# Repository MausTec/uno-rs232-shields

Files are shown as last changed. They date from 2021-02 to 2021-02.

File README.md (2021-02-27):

# Arduino RS232 Shields

This repository contains DTE and DCE shields for the Arduino Uno and compatible devices. These shields use the hardware
serial ports and provide a 9 pin serial connector for interfacing with older electronics. Each shield has a few
variants:

- Standard Variant: RS232 exits the back (notch side) of the Arduino
- Reverse Variant: RS232 exits the front (USB side) of the Arduino

## Are these for sale?

Oh you betcha! DIY Kits and assembled shields will be available on [maustec.io](https://maustec.io).

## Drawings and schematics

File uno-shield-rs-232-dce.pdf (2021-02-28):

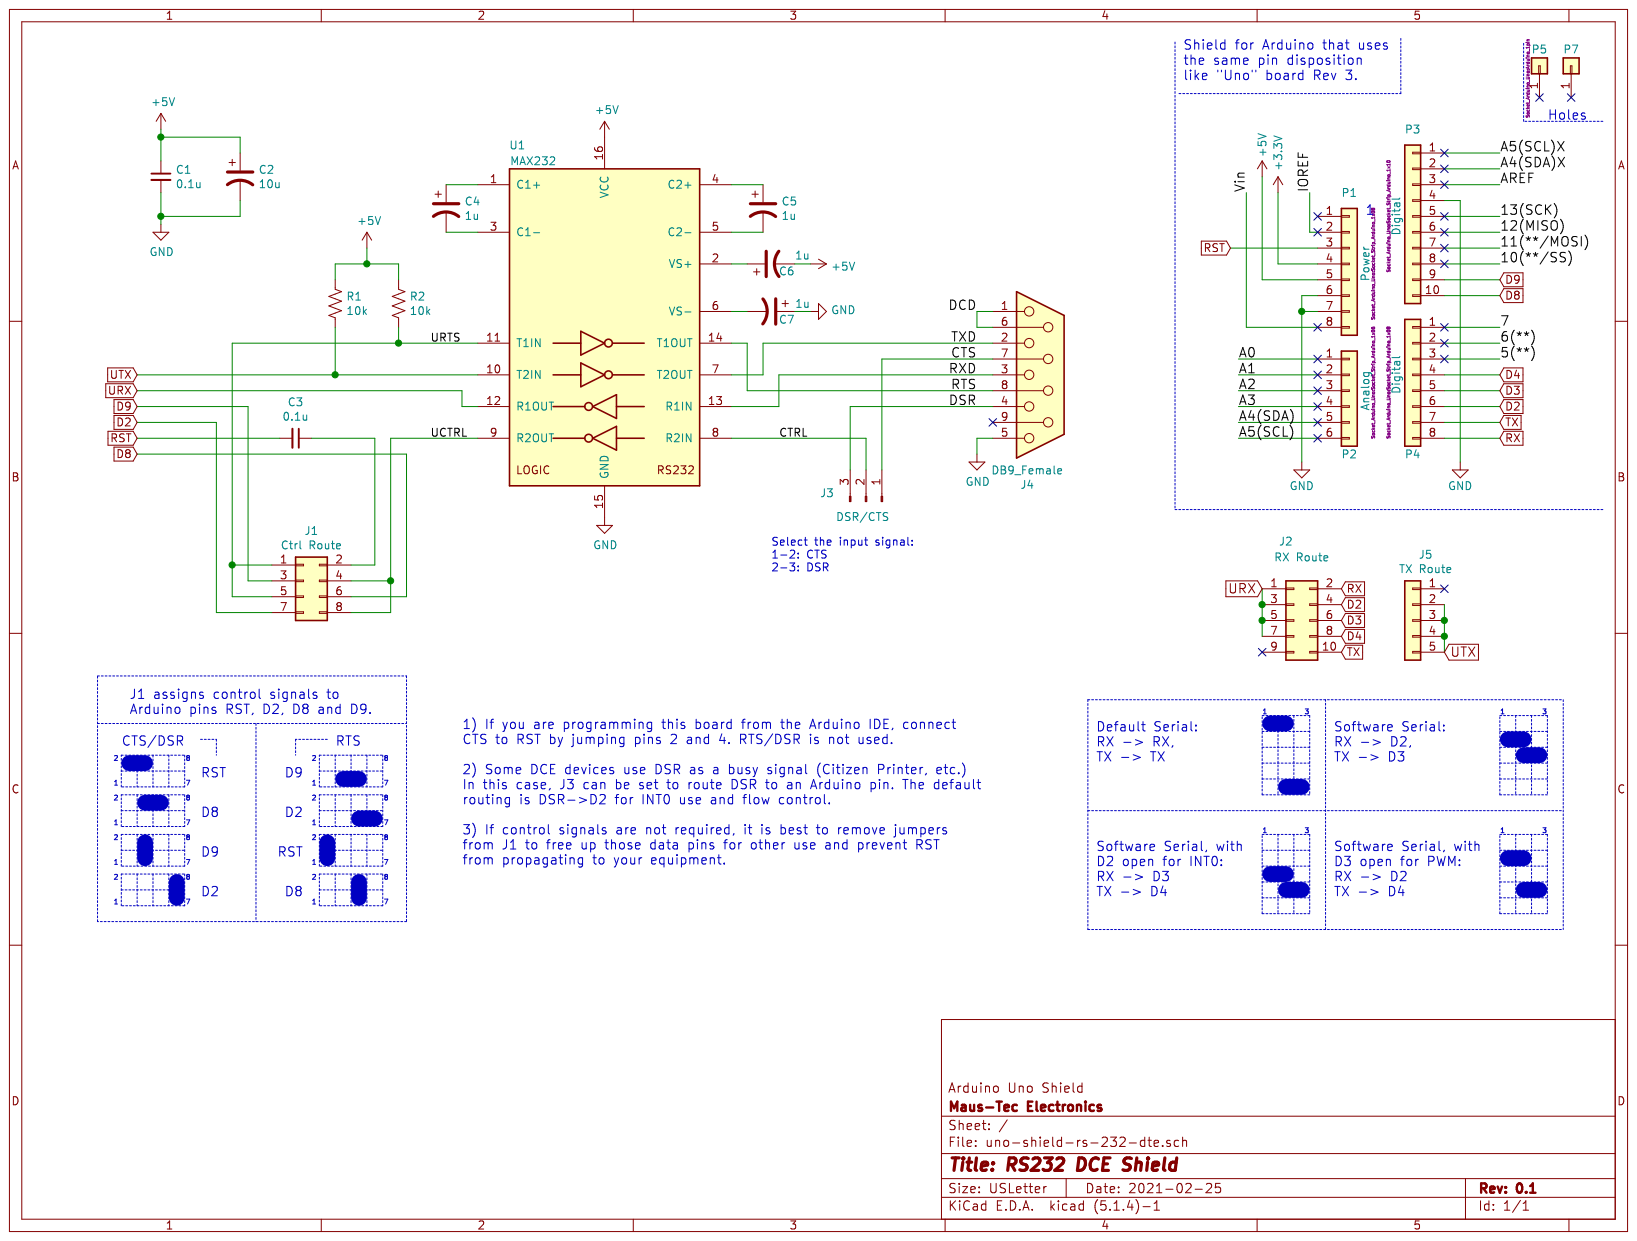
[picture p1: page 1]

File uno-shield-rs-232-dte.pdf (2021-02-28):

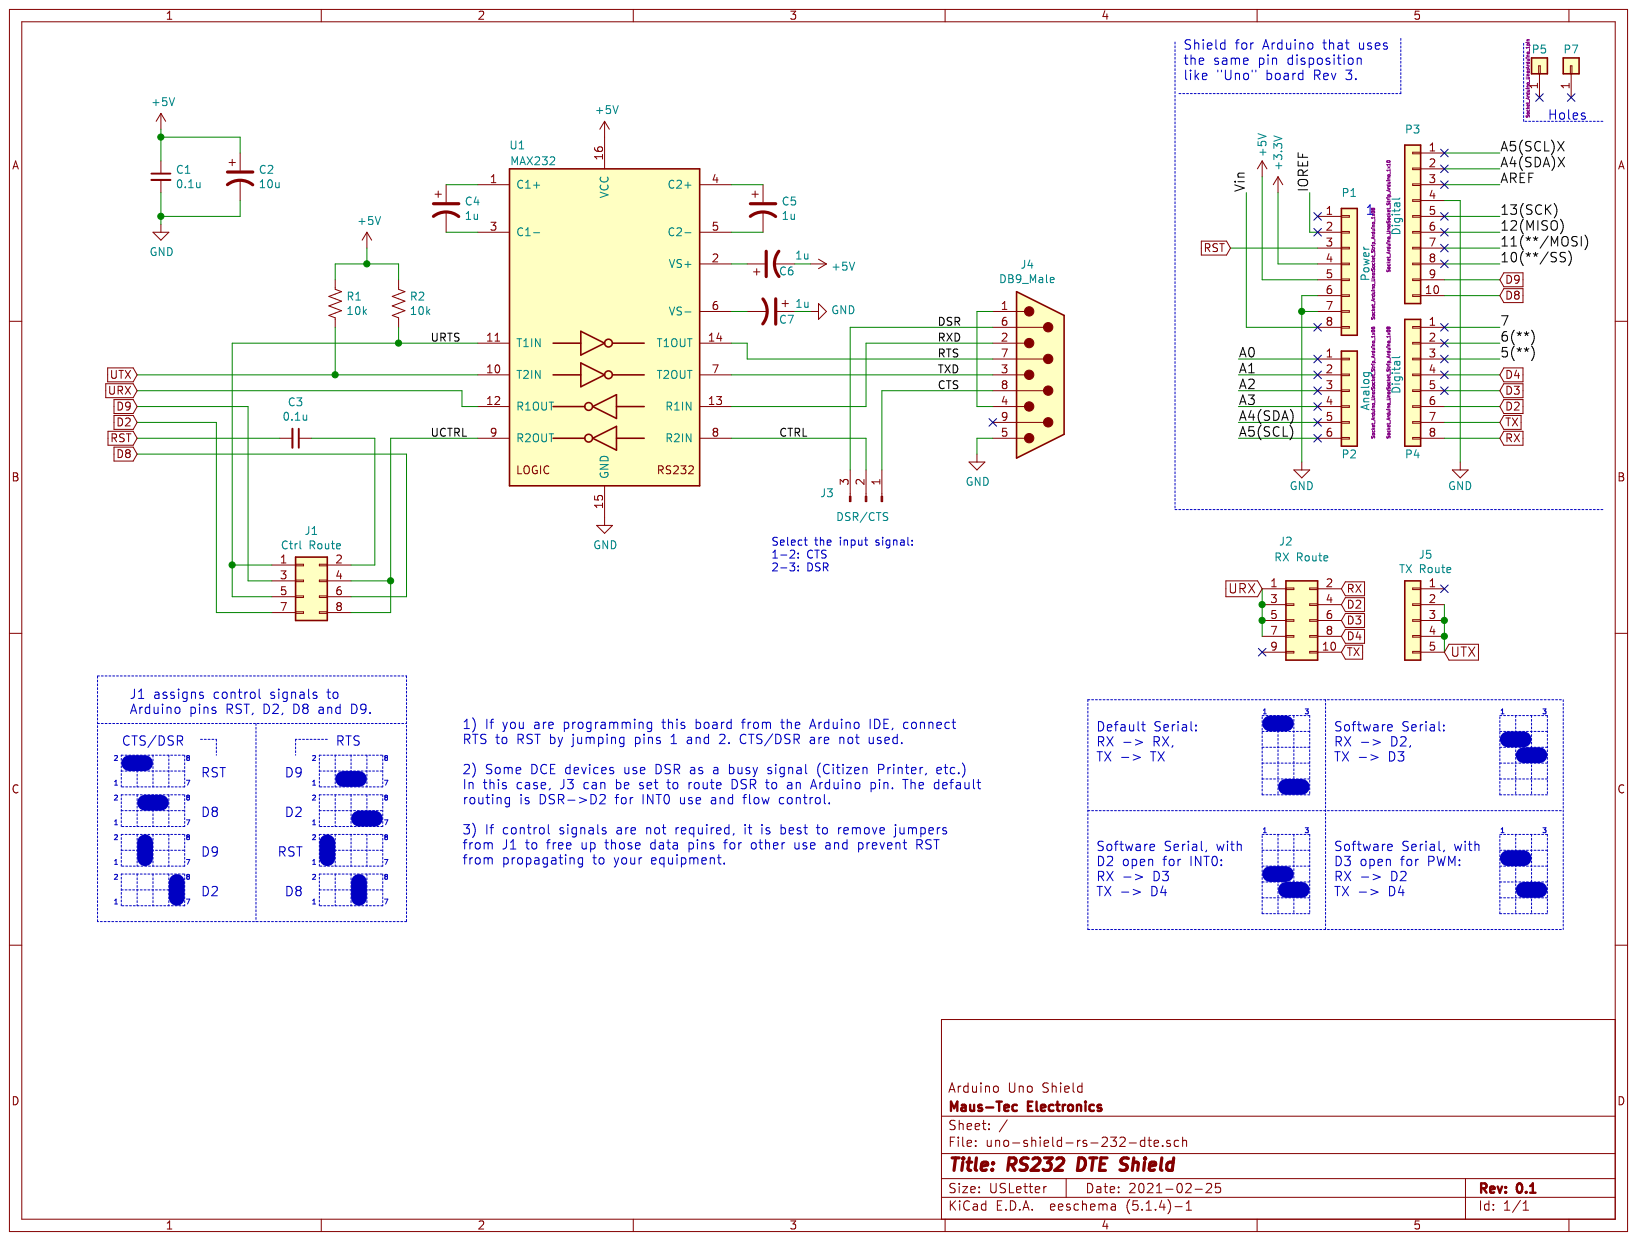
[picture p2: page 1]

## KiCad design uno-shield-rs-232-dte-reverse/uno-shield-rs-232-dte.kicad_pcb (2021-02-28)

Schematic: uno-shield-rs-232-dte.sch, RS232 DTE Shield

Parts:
C1, C3: 0.1u; C_Disc_D5.0mm_W2.5mm_P2.50mm
C2: 10u; CP_Radial_D6.3mm_P2.50mm
C4, C5, C6, C7: 1u; CP_Radial_D4.0mm_P2.00mm
J1: Ctrl Route; PinHeader_2x04_P2.54mm_Vertical
J2: RX Route; PinHeader_2x05_P2.54mm_Vertical
J3: DSR/CTS; PinHeader_1x03_P2.54mm_Vertical
J4: DB9_Male; DSUB-9_Male_Horizontal_P2.77x2.84mm_EdgePinOffset4.94mm_Hou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
J5: TX Route; PinHeader_1x05_P2.54mm_Vertical
P1: Power; Socket_Strip_Arduino_1x08
P2: Analog; Socket_Strip_Arduino_1x06
P3: Digital; Socket_Strip_Arduino_1x10
P4: Digital; Socket_Strip_Arduino_1x08
P5, P7: CONN_01X01; Arduino_1pin
R1, R2: 10k; R_Axial_DIN0207_L6.3mm_D2.5mm_P10.16mm_Horizontal
U1: MAX232; DIP-16_W7.62mm_LongPads

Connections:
+3V3: P1.4
+5V: C1.1, C2.1, C6.2, P1.5, R1.1, R2.1, U1.16 (VCC)
/5(**): P4.3
/6(**): P4.2
/7: P4.1
/10(**/SS): P3.8
/11(**/MOSI): P3.7
/12(MISO): P3.6
/13(SCK): P3.5
/A0: P2.1
/A1: P2.2
/A2: P2.3
/A3: P2.4
/A4(SDA): P2.5
/A4(SDA)X: P3.2
/A5(SCL): P2.6
/A5(SCL)X: P3.1
/AREF: P3.3
/CTRL: J3.2, U1.8 (R2IN)
/CTS: J3.1, J4.8
/DSR: J3.3, J4.6
/IOREF: P1.2
/RTS: J4.7, U1.14 (T1OUT)
/RXD: J4.2, U1.13 (R1IN)
/TXD: J4.3, U1.7 (T2OUT)
/UCTRL: J1.4, J1.8, U1.9 (R2OUT)
/URTS: J1.1, J1.5, R2.2, U1.11 (T1IN)
/Vin: P1.8
D2: J1.7, J2.4, P4.6
D3: J2.6, P4.5
D4: J2.8, P4.4
D8: J1.6, P3.10
D9: J1.3, P3.9
GND: C1.2, C2.2, C7.1, J4.5, P1.6, P1.7, P3.4, U1.15 (GND)
unnamed: C3.1, J1.2
unnamed: C4.1, U1.1 (C1+)
unnamed: C4.2, U1.3 (C1-)
unnamed: C5.1, U1.4 (C2+)
unnamed: C5.2, U1.5 (C2-)
unnamed: C6.1, U1.2 (VS+)
unnamed: C7.2, U1.6 (VS-)
unnamed: J4.1, J4.4
RST: C3.2, P1.3
RX: J2.2, P4.8
TX: J2.10, P4.7
URX: J2.1, J2.3, J2.5, J2.7, U1.12 (R1OUT)
UTX: J5.2, J5.3, J5.4, J5.5, R1.2, U1.10 (T2IN)

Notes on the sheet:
Holes
Shield for Arduino that uses the same pin disposition like "Uno" board Rev 3.
Select the input signal: 1-2: CTS 2-3: DSR
2 8 1 7
J1 assigns control signals to Arduino pins RST, D2, D8 and D9.
CTS/DSR
RTS
RST
1) If you are programming this board from the Arduino IDE, connect RTS to RST by jumping pins 1 and 2. CTS/DSR are not used. 2) Some DCE devices use DSR as a busy signal (Citizen Printer, etc.) In this case, J3 can be set to route DSR to an Arduino pin. The default routing is DSR->D2 for INT0 use a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
1 3
Default Serial: RX -> RX, TX -> TX
Software Serial: RX -> D2, TX -> D3
Software Serial, with D3 open for PWM: RX -> D2 TX -> D4
Software Serial, with D2 open for INT0: RX -> D3 TX -> D4

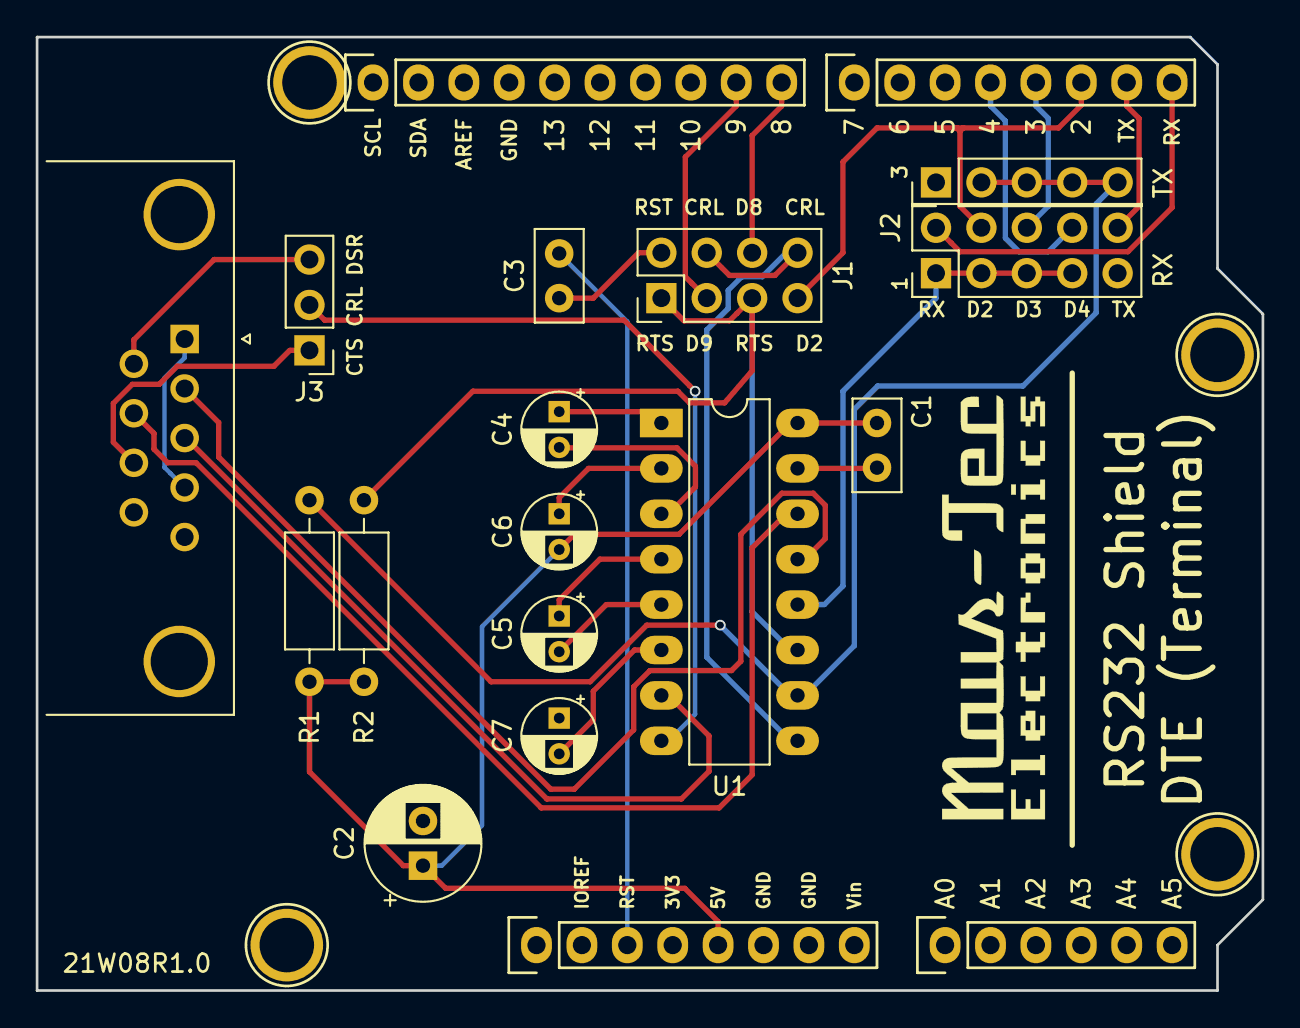
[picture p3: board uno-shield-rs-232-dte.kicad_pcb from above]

Board: 2 copper layers, 68.6 x 53.3 mm, 23 parts (0 on the bottom side), 28 nets.

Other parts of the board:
P6, P8: CONN_01X01; Arduino_1pin

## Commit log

2021-02-27 Add DTE shield.
    [uno-shield-rs-232-dte.kicad_pcb, uno-shield-rs-232-dte.sch]
2021-02-27 Add DTE-Reverse
    [uno-shield-rs-232-dte.kicad_pcb, uno-shield-rs-232-dte.sch]
2021-02-28 Adjust DTE shield to allow UART routing.
    [uno-shield-rs-232-dte.kicad_pcb, uno-shield-rs-232-dte.sch]
2021-02-28 Propagate signal routing changes to DTE-R shield.
    [uno-shield-rs-232-dte.kicad_pcb, uno-shield-rs-232-dte.sch]
2021-02-28 Add DCE revision.
    [uno-shield-rs-232-dce.kicad_pcb, uno-shield-rs-232-dce.sch]
2021-02-28 Add DCE reverse revision.
    [uno-shield-rs-232-dce.kicad_pcb, uno-shield-rs-232-dce.sch]
2021-02-28 Generate gerbers locally.
    [uno-shield-rs-232-dce.kicad_pcb, uno-shield-rs-232-dte.kicad_pcb]
